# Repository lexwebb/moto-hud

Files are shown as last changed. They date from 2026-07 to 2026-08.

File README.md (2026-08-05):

# Moto HUD

Motorcycle e-ink turn-by-turn HUD: Android companion reads turn-by-turn from **OsmAnd** (AIDL or embedded Full Library) or Google Maps notifications + media, sends them over BLE to a Go service on a Raspberry Pi Zero that renders a sparse UI on a 250×122 panel ([Inky pHAT](https://shop.pimoroni.com/products/inky-phat) or [Waveshare 2.13″ B/W e-Paper HAT](https://www.waveshare.com/2.13inch-e-paper-hat.htm); optional LCD).

```
OsmAnd app  ──► AIDL (default) ───────────────┐
:osmand DF  ──► RoutingHelper (on-demand) ────┼─► Android app ──BLE──► Go (Pi) ──► display HAT
Google Maps ──► NotificationListener ─────────┤         ▲
Music apps  ──► MediaController ──────────────┘         │
Buttons (GPIO) ─────────────────────────────────────────┘  cmd notify
```

## Repo layout

| Path | Purpose |
|---|---|
| [`protocol/`](protocol/) | BLE UUIDs + JSON message schema |
| [`pi/`](pi/) | Go HUD service, mock injector, systemd unit |
| [`android/`](android/) | Kotlin companion app |
| [`enclosure/`](enclosure/) | OpenSCAD bench case (CAD + mesh exports) |
| [`site/`](site/) | Astro project site (GitHub Pages) |
| [`docs/adr/`](docs/adr/) | Architecture Decision Records |
| [`CONTEXT.md`](CONTEXT.md) | Domain language / glossary |

## Project site (GitHub Pages)

Public demos: enclosure 3D viewer, design HUD kit, WASM ride emulator.

**https://lexwebb.github.io/moto-hud/**

```bash
cd site
npm install
npm run build:wasm   # optional locally; needs Go — CI builds it for Pages
npm run dev          # http://localhost:4321/moto-hud/
```

Deploy: push to `main` (workflow `.github/workflows/pages.yml`). One-time: repo **Settings → Pages → Source: GitHub Actions**.

Go-backed live `/preview` (frame.png / fonts) is still local-only via `./scripts/emu.sh`.

Full ride simulation with Leaflet (OSM) + HUD driven by the same Go core (WASM preferred, HTTP fallback):

```bash
./scripts/emu.sh
# open http://127.0.0.1:8787/emulator/
```

- Map animates a real OSRM street route Whitehall → Farringdon (`web/emulator/routes/whitehall-farringdon.json`)
- Each tick posts nav distance/maneuver into the HUD
- Virtual Prev/Next/Action buttons
- **Device** picker: Inky 4-colour (~20s BWRY wipe), Waveshare B/W (partial ~0.3s, full ~2s every 5), or Display HAT Mini LCD (instant letterbox); e-ink modes use **≈ nearest 50 m** and redraw ~every **50 m**
- Build WASM only: `./scripts/build-wasm.sh` → `web/emulator/motohud.wasm` (gitignored, ~15MB)

## Hardware hosts

`motohud` talks to the panel/buttons/phone through `pi/internal/platform` ports so adapters can be swapped. Canonical compose is always **250×122 gray**; backends map to hardware.

| `-host` | Screen | Controls | Phone link |
|---|---|---|---|
| `auto` (default) | PNG, or Inky if `-inky` | keyboard / GPIO | BLE stub (or `-tags ble`) |
| `png` | PNG file | keyboard / GPIO | BLE stub |
| `inky` | Inky pHAT (kept for existing boards) | GPIO | BLE |
| `waveshare` | Waveshare 2.13″ B/W e-Paper | GPIO | BLE |
| `lcd` | Display HAT Mini 320×240 (letterboxed) | GPIO (Action→16) | BLE |
| `emu` | memory (+ optional PNG) | channel (injectable) | loopback linked |
| `test` | memory | channel | loopback |

```bash
./bin/motohud -demo -host png -out out/hud.png -http :8787
./bin/motohud -host inky -inky          # existing Inky on the Pi
./bin/motohud -host waveshare           # Waveshare 2.13 B/W
./bin/motohud -host lcd                 # Display HAT Mini (optional)
```

The browser emulator uses Go WASM (`pi/cmd/motohud-wasm`) for the HUD core, with HTTP → `-host emu` as fallback.

Reference pack from Claude Design lives in [`design/`](design/) (tokens, React kit, guidelines). **Production type is Terminus Bold**, not the kit’s browser monospace stand-in. Interactive mock: open `design/ui_kits/hud/index.html` via a static server.

Layouts live in [`assets/hud/`](assets/hud/) as 250×122 SVG with `{{placeholders}}`.

```bash
cd /Users/lex/src/moto-hud
./bin/motohud -demo -out out/hud.png
# open http://127.0.0.1:8787/preview/   ← 1-bit /frame.png @ 2×
# SVG source (debug): http://127.0.0.1:8787/frame.svg
```

**Typography (SVG + Terminus Bold):** Templates in `assets/hud/*.svg` use `<text data-pixel="12x24" font-size="24" …>`. At render those become **1×1 pixel `<rect>`s** from Terminus Bold BDFs; arrows are stroked then hard-thresholded to 1-bit. The web preview shows **`/frame.png`** (same raster as the Pi). Compare faces at `/preview/fonts.html`.

| Role | `data-pixel` | Face |
|---|---|---|
| Distance | `16x32` | `ter-u32b` |
| Road / titles | `12x24` | `ter-u24b` |
| Body / ETA | `8x16` | `ter-u16b` |
| Meta | `6x12` | `ter-u12b` |

Only those four sizes — no runtime scaling. License: SIL OFL 1.1 (`assets/fonts/terminus/OFL.TXT`).

```bash
cd pi
go run ./cmd/motohud -demo -out ../out/hud.png -http :8787
# another terminal:
go run ./cmd/mock-nav -scenario approach
# open out/hud.png — updates when distance crosses 500/200/100/50/20 m
```

Keyboard buttons while `motohud` runs: `p`/`n`/`a` short, `P`/`N`/`A` long (+ Enter).

**HUD UI layer** (`pi/internal/hudui`, ADR 0010–0012): [templ](https://templ.guide) screen components, integer flex layout helpers, and `hud.RenderEngine` for tier-aware draws (distance-only patches when the refresh orchestrator allows). Regenerate after editing `.templ` files: `./scripts/generate-hudui.sh`.

HTTP injector (also used by `mock-nav`):

- `POST /nav` — JSON nav message
- `POST /media` — JSON media message
- `POST /button` — body `prev` \| `next` \| `prev_long` \| `next_long` \| `action` \| `action_long` \| `skip_prev` \| `skip_next`

## Pi Zero + display HATs

### Recommended boards

| Role | Board | Notes |
|---|---|---|
| **Preferred new e-ink** | [Waveshare 2.13″ e-Paper HAT (black/white)](https://www.waveshare.com/2.13inch-e-paper-hat.htm) or [HAT+](https://www.waveshare.com/2.13inch-e-paper-hat-plus.htm) | Same 250×122 canvas; ~2s full / ~0.3s partial. **Do not** buy colour (B/G) variants — ~15s+ refresh. |
| Existing / regression | Inky pHAT **black/white** | Still supported via `-host inky`. B/W Inky is discontinued; 4-colour Inky is too slow for nav (~15–20s). |
| Optional LCD | [Pimoroni Display HAT Mini](https://shop.pimoroni.com/products/display-hat-mini) | 320×240 IPS; HUD letterboxed. Instant refresh; backlight + sun glare trade-offs. |

1. Enable SPI: `sudo raspi-config` → Interface → SPI (`dtparam=spi=on`).

   - **Waveshare 2.13″ HAT:** use default SPI0 **with hardware CE0**. Do **not** add `dtoverlay=spi0-0cs` — that leaves CS floating high and the panel stays blank while the driver still reports “ready”.
   - **Inky pHAT:** may need `dtoverlay=spi0-0cs` (soft CS); see Pimoroni docs.
   - Display HAT Mini uses **SPI0 CE1**; `dtparam=spi=on` is enough.

2. Cross-compile for the Pi (Docker; any host OS):

   ```bash
   ./scripts/build-armv6.sh           # stub BLE (pure Go)
   ./scripts/build-armv6.sh --ble     # real BlueZ peripheral (CGO)
   ./scripts/build-armv6.sh --ble --deploy 10.12.194.1   # scp + restart
   ```

   On-device `go build -tags ble` still works if you have Go + `libbluetooth-dev` on the Pi, but Docker is the supported path.

3. Run with hardware display:

   ```bash
   ./bin/motohud -host waveshare -out /tmp/hud.png -http :8787
   # or: -host inky    /  -host lcd
   ```

4. Install systemd unit from [`pi/systemd/motohud.service`](pi/systemd/motohud.service) (adjust paths/user).

**SD card from a Mac (Pi Zero W + Waveshare):** use **Raspberry Pi OS Lite** (32-bit / armhf) — not desktop. Flash + customise:

```bash
./scripts/flash-lite.sh --disk disk12 \
  --user motohud --password motohud \
  --ssid 'YourWifi' --psk '…' \   # 2.4 GHz only on Zero W
  --bwr                           # only if you have HAT (B) red/black/white
```

Or, with `bootfs` already mounted on an existing Lite card:

```bash
./scripts/prepare-bootfs.sh --boot /Volumes/bootfs \
  --user motohud --password motohud \
  --ssid 'YourWifi' --psk '…' \
  --bwr   # HAT (B) only
```

That writes an ARMv6 `motohud` binary, Waveshare SPI (hardware CE0 — never `spi0-0cs`), official USB Ethernet gadget (`rpi-usb-gadget`), cloud-init NetworkManager Wi‑Fi, and a firstrun installer. Use the Zero’s **data** micro‑USB port (next to HDMI), not PWR. Wait for **two** boots (~2–4 min).

**SSH over USB (recommended first):** macOS Sequoia/Tahoe cannot Internet‑Share to this gadget (`CHANNEL_IO` → no `bridge100`). Skip Sharing; run:

```bash
./scripts/macos-usb-gadget.sh   # 10.12.194.2/28, no gateway; Wi‑Fi stays default route
ssh motohud@10.12.194.1         # Pi SHARED address
```

Then mDNS / Wi‑Fi: `ssh motohud@motohud.local`. HTTP: `http://10.12.194.1:8787/`.

**BLE (phone link):** `flash-lite` / `prepare-bootfs` build a BlueZ binary via Docker by default. To refresh a running Pi:

```bash
./scripts/build-armv6.sh --ble --deploy 10.12.194.1
```

Android companion scans for BLE name **MotoHUD**.

### Display pin maps (BCM)

Avoid these for buttons:

| Backend | DC | RST | BUSY / other | SPI |
|---|----|-----|---|-----|
| Inky | 22 | 27 | BUSY 17 | SPI0.0 |
| Waveshare 2.13 | 25 | 17 | BUSY 24 | SPI0.0 |
| Display HAT Mini | 9 | — | BL **13**, CE1 | SPI0.1 |

### Button wiring (BCM)

Active-low with internal pull-ups. Full soldering dummies guide, enclosure BOM, and Waveshare 8-pin note: [`docs/BUTTONS.md`](docs/BUTTONS.md). Caps + tactile wells: [`enclosure/README.md`](enclosure/README.md).

| Button | BCM (inky / waveshare) | BCM (`-host lcd`) | Role |
|---|---|---|---|
| Prev | 5 | 5 (HAT A) | Previous screen / prev track on Media |
| Next | 6 | 6 (HAT B) | Next screen / next track on Media |
| Action | 13 | **16** (HAT X) | Context action; **long-press** → Nav home |

On Display HAT Mini, BCM 13 is the backlight, so Action automatically remaps to button X (16).

Screens: **Nav** → **Media** → **Status**.

- Prev/Next (not on Media) → change screen  
- Media + short Prev/Next → skip track (`prev_track` / `next_track`)  
- Media + long Prev/Next → change screen  
- Media + Action → `play_pause`  
- Status + Action → force full redraw  
- Long-press Action → Nav home

## Android companion

Open [`android/`](android/) in Android Studio, sync Gradle, side-load on a phone (or emulator).

**Delivery model** ([ADR 0006](docs/adr/0006-engine-agnostic-nav-android-osmand-ios-mapkit.md)):

| Piece | Size (approx) | Nav |
|---|---|-----|
| Base APK | ~6.5 MB | External [OsmAnd](https://play.google.com/store/apps/details?id=net.osmand) via AIDL + Maps scrape fallback |
| On-demand `:osmand` module | ~215 MB uncompressed (arm64-only, mini basemap stripped); Play compresses further | OsmAnd Full Library — lanes, then-next, ETA |
| Full debug `.aab` (base+module) | ~100 MB | both modules packaged; Play still delivers base first |
| Region maps | downloaded in OsmAnd UI | not bundled |

```bash
# base APK (AIDL)
gradle :app:installDebug

# Play / local module testing — build an App Bundle, then:
gradle :app:bundleDebug
# bundletool build-apks --bundle=app/build/outputs/bundle/debug/app-debug.aab \
#   --output=/tmp/motohud.apks --local-testing
# bundletool install-apks --apks=/tmp/motohud.apks
```

1. Install **OsmAnd** for the default AIDL path (or skip if you only use Maps scrape).
2. Optional: tap **Download rich OsmAnd nav** → restart when prompted → **Open OsmAnd map** → download your region → navigate (lanes on the HUD).
3. Grant **notification access** (media + Maps/OsmAnd enrichment).
4. Tap **Start HUD link** — starts the nav engine, scans for BLE **MotoHUD**.

Size knobs: arm64-only natives, Play Feature Delivery on-demand module, `World_basemap_mini.obf` stripped (maps stay dynamic), AAB ABI/language/density splits.

If using Maps and fields are empty, disable Maps **Live Updates** / **Live info** notification categories. iOS will use MapKit later (no self-hosted Valhalla).

**Dev HTTP (no Pi BLE):** enable **Also POST nav/media over HTTP** and set the base URL (emulator → host is `http://10.0.2.2:8787`). Run `motohud -host png -http :8787` on the PC. BLE scan still runs; HTTP posts happen whenever nav/media update. See [`protocol/README.md`](protocol/README.md).

Unit tests: `gradle :app:testDebugUnitTest`.

## CI

[`.github/workflows/ci.yml`](.github/workflows/ci.yml) runs `go test ./...` in `pi/` and Android unit tests on push/PR.

## Notes

- Panel refresh is full-frame on Inky (~20s). Waveshare uses partial updates (~0.3s, no flicker) with a full refresh (~2s) every 5 frames to clear ghosting. The Go compositor only redraws on maneuver/road changes, coarse distance thresholds, screen changes, or force.
- Audio stays on the phone → helmet Bluetooth; the Pi is display + button bridge only.

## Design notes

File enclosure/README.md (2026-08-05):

# Moto HUD enclosure (bench prototype)

Parametric OpenSCAD clamshell for a **Raspberry Pi Zero + e-ink HAT** stack (Inky or Waveshare 2.13″). Buttons are a right-hand rail: printed mushroom caps over 6×6 mm tactiles by default. No bike mount or full weather sealing yet — fit the boards and switches first.

## Files

| Path | Purpose |
|---|---|
| [`moto_hud_case.scad`](moto_hud_case.scad) | Parametric model (`part`: `assembly` / `base` / `lid` / `caps`) |
| [`preview.html`](preview.html) | Standalone Three.js orbit viewer (dev convenience) |
| [`exports/`](exports/) | STL / GLB meshes for print + site |

The project site hosts the enclosure viewer at
**https://lexwebb.github.io/moto-hud/enclosure/** (copies `exports/assembly.glb` at build time).
After regenerating meshes, commit the updated GLB so CI/Pages pick it up.

## Buttons

| `button_mode` | Lid | Base | Extra print |
|---|-----|---|---|
| **`cap`** (default) | Stem shafts + outer flange counterbore | 6×6 tactile wells + wire channels into the board cavity | `part="caps"` — three ~11 mm mushroom actuators |
| **`panel8`** | 8.2 mm holes for high-head metal panel switches | No wells | None |

Order along +Y (rail on the **right**, screen upright): **Prev → Next → Action** (BCM 5 / 6 / 13). Wiring guide: [`docs/BUTTONS.md`](../docs/BUTTONS.md).

### Cap fit loop

1. Print base, lid, and caps. Dry-fit stems — they should slide, not bind (`stem_clear` / `print_tol`).
2. Seat 6×6 momentary NO tactiles in the wells; route pigtails through the wire channels.
3. Drop caps in from the outside (flange in the counterbore). Stem should click the tactile before bottoming on the lid.
4. If the click is early/late, change **`stem_len`** or **`well_depth`** only — do not change BCM pins.
5. Caliper the real tactile height into **`tactile_h`** after you buy parts.

Caps: TPU (~95A) for a softer dome, or PETG for a rigid v0. Export with stem toward the bed (`caps_sprue` lifts geometry so stem tips sit near Z=0) or flip in the slicer.

## Dimensions (defaults)

Tune the Customizer / parameter block after caliper checks:

- Pi Zero board: **65 × 30 mm**, M2.5 holes inset **3.5 mm**
- Stack height (Pi + header + HAT): **14 mm** (`stack_h`)
- Usable glass: **48.5 × 23.8 mm** (`window_w` / `window_d`)
- Wall / floor / lid: **2 mm**; lateral clearance **0.4 mm**
- Right-hand **button rail**: **12 mm** (`button_rail`); pitch **12 mm**; cap OD **11 mm**

## OpenSCAD

1. Install [OpenSCAD](https://openscad.org/) (2021.01+).
2. Open `moto_hud_case.scad`.
3. Set **part** to `assembly` for preview (optional **explode** to lift the lid).
4. **F5** preview, **F6** render.

### Export STLs (GUI)

1. Set `part` to `base`, `lid`, or `caps`, **F6**, then **File → Export → Export as STL**.
2. For the browser preview, export `part = "assembly"` to `exports/assembly.stl`, then convert to GLB (below).

### Export STLs (CLI)

From this directory (quoting matters on Windows `cmd`):

```bat
"C:\Program Files\OpenSCAD\openscad.exe" -D "part=\"base\"" -o exports/base.stl moto_hud_case.scad
"C:\Program Files\OpenSCAD\openscad.exe" -D "part=\"lid\"" -o exports/lid.stl moto_hud_case.scad
"C:\Program Files\OpenSCAD\openscad.exe" -D "part=\"caps\"" -o exports/caps.stl moto_hud_case.scad
"C:\Program Files\OpenSCAD\openscad.exe" -D "part=\"assembly\"" -o exports/assembly.stl moto_hud_case.scad
```

macOS / Linux:

```bash
openscad -D 'part="base"' -o exports/base.stl moto_hud_case.scad
openscad -D 'part="lid"' -o exports/lid.stl moto_hud_case.scad
openscad -D 'part="caps"' -o exports/caps.stl moto_hud_case.scad
openscad -D 'part="assembly"' -o exports/assembly.stl moto_hud_case.scad
```

Or run [`export_meshes.sh`](export_meshes.sh) / [`export_meshes.ps1`](export_meshes.ps1) (includes `caps` + GLB).

### Assembly GLB for the browser viewer

OpenSCAD does not export GLB; convert the assembly STL (needs `pip install trimesh`):

```bash
python -c "import trimesh; m=trimesh.load('exports/assembly.stl', force='mesh'); from trimesh.visual.material import PBRMaterial; from trimesh.visual import TextureVisuals; m.visual=TextureVisuals(material=PBRMaterial(baseColorFactor=[0.72,0.74,0.76,1], metallicFactor=0.05, roughnessFactor=0.55)); m.export('exports/assembly.glb')"
```

## Browser preview

Primary viewer: the Astro site page (`site/` → `/enclosure/` on Pages).

Standalone convenience viewer ([`preview.html`](preview.html)) still works:

```bash
# from repo root
python -m http.server 8765 --directory enclosure
# open http://127.0.0.1:8765/preview.html
```

After changing the `.scad`, re-export meshes (including `assembly.glb`) and refresh / redeploy the site.

## Print notes

- Print **base**, **lid**, and **caps** separately. Lid export is already flipped upright with lip up.
- Start with the default clearances; if the board is tight, bump `clearance` / `print_tol` by 0.1–0.2 mm.
- USB cutout sized for Pi Zero micro-USB power; widen `usb_w` / `usb_h` for Zero 2 W USB-C if needed.

## Next (not in this pass)

- Bike mount interface (after you measure the mount area)
- Weather sealing / lens / silicone skirt over caps
- Handlebar remote pod (large switches; same BCM map)

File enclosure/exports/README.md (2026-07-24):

# Exported meshes for print + browser preview.
# Regenerate from ../moto_hud_case.scad (see ../README.md).

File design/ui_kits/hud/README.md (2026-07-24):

# HUD UI Kit

Interactive walkthrough of all six delivered screens at true 250×122 (scaled 2.4× for viewing). Buttons below the panel simulate the device's three physical controls: Prev / Next / Action, with mousedown+hold (~500ms) standing in for long-press.

Screens: NavActiveNoRibbon, NavActiveRibbon, NavIdle, MediaFocus, StatusDiagnostics, NavMediaHybrid — each a thin composition of the `components/` primitives (ManeuverGlyph, DistanceReadout, RoadRibbon, etc). No new visual logic lives here beyond layout.

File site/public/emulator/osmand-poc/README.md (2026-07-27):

# OsmAnd junction proof (no phone)

Off-device proof that **OsmAnd-java** (same library the embedded Full Library module uses) can supply junction IR inputs: `attachedRoutes`, `highway`, `oneway`, bearings — without the tagged Overpass bake.

## Result (Whitehall → Farringdon)

See [`osmand-junction-dump.json`](osmand-junction-dump.json). Summary from last run:

- **9** turn segments; **7** with non-empty `getAttachedRoutes(start)`
- **`dual_carriageway` tag hits: 0** — tag is not in OBF routing encoding
- **`dual_inferred: 3`** — Whitehall (×2) + Northumberland Avenue via spatial OBF scan
- Side streets / Farringdon / Embankment: no dual (aligned with OSM tags; Embankment is physically dual but untagged)

## Dual inference rules (hardened)

`attachedRoutes` alone miss clean duals (parallel carriageways often share no nodes). Algorithm:

1. **Turn corridor only** — skip residential / `*_link` turn segments.
2. **Local arms** — route segment + attachments at every point index.
3. **Spatial OBF scan** (~50 m) via `buildSearchRouteRequest` / `loadRouteIndexData` — required for Whitehall-class duals.
4. **Match** when:
   - both car highways (exclude footway/cycleway/pedestrian)
   - lateral cross-track sep **10–22 m**
   - opposite travel bearings (≥150°)
   - **and** at least one `oneway≠0` (both-bidirectional parallels → Farringdon FP)
5. **Opposite oneway** means both oneway + opposite bearings (each dual carriageway is typically `oneway=+1` along its own geometry — do **not** require `+1` vs `-1` signs).
6. Never same-direction parallels (Fleet Street).

## Reproduce

Prereqs: JDK 17+, network once for Overpass + MapCreator download.

```bat
:: from site/
node scripts/export-whitehall-osm.mjs

:: download MapCreator if missing (~150MB)
curl -fL -o public/emulator/osmand-poc/OsmAndMapCreator-main.zip https://download.osmand.net/latest-night-build/OsmAndMapCreator-main.zip
:: extract to public/emulator/osmand-poc/mapcreator/

cd public/emulator/osmand-poc/mapcreator
utilities.bat generate-roads ..\whitehall-farringdon.osm

cd ..
dump-osmand-junction.bat
```

## What this means for the plan

| Need | Source on phone (Full Library) | Proven here? |
|---|---|---|
| Turn class | `TurnType` | Yes (KL/TR/TL/TSLR/…) |
| Side arms | `RouteSegmentResult.getAttachedRoutes` | Yes |
| Highway class / ramps | `RouteDataObject.getHighway()` | Yes (`primary_link`, etc.) |
| Divided road | Spatial OBF + oneway/bearing | **Yes** (no tag) |
| Full OSM bake | Not required | Confirmed unnecessary for junction node |

AIDL path still cannot do this; only embedded OsmAnd.

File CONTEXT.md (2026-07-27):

# Moto HUD — domain language

Terms meaningful to the product. Implementation details live in code and ADRs.

| Term | Meaning |
|---|---|
| **Companion** | Phone app that ingests navigation + media and sends HUD state to the Pi over BLE (or dev HTTP). |
| **Hub** | Go service on the Pi: applies nav/media, composites frames, drives the panel, handles buttons. |
| **Canvas** | Logical 250×122 grayscale HUD frame before a display backend maps it to hardware. |
| **Host / backend** | Panel adapter selected with `-host` (`inky`, `waveshare`, `lcd`, `png`, …). |
| **Nav engine** | Platform-specific source of turn-by-turn data that fills the shared `nav` protocol (e.g. OsmAnd on Android, MapKit on iOS). |
| **Maneuver** | Next turn class on the wire: `left`, `right`, `slight_*`, `straight`, `u_turn`, `roundabout`, `arrive`, `depart`, `unknown`. |
| **Lanes** | Optional per-lane guidance array on `nav`; omitted when the engine cannot provide it. |
| **Refresh gate** | Policy that limits e-ink redraws (maneuver/road change, coarse distance buckets, force). |
| **Partial / full refresh** | Waveshare B/W update modes (~0.3s quiet vs ~2s wipe); full after every N partials. |
| **Junction IR** | Semantic turn-scene description (`nav.junction`) drawn as idealized templates by `kind`; replaces geographic minimap polylines ([ADR 0013](docs/adr/0013-junction-ir-replaces-minimap.md)). |
| **Ribbon** | Secondary left-column corridor schematic when neither junction nor synthesizable maneuver exists. |
| **Link** | BLE (or HTTP injector) connection carrying `nav`, `media`, `cmd`, `heartbeat`. |

Decisions: [`docs/adr/`](docs/adr/).

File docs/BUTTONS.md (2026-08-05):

# Button wiring

Canonical buttons are active-low to GND with software pull-ups. Display HATs reserve some GPIOs — do not reuse those for buttons.

The Waveshare 2.13″ **PH2.0 8-pin cable is display-only** (VCC/GND/SPI/DC/RST/BUSY). It is **not** a button bus. Wire external momentary NO switches to free GPIOs instead.

## Default button map (Inky / Waveshare)

| Function | BCM | Physical pin (Pi Zero underside) | Suggested wire |
|---|-----|---|---|
| Prev | 5 | **29** | Green |
| Next | 6 | **31** | Yellow |
| Action | 13 | **33** | Blue |
| Common GND | — | **30** or **34** | Black |

| Gesture | Effect |
|---|---|
| Short Prev/Next | Change screen (or skip track on Media) |
| Long Prev/Next (≥800 ms) | Always change screen |
| Short Action | Context (play/pause or force redraw) |
| Long Action | Return to Nav home |

Enclosure rail order (+Y, rail on the right): **Prev → Next → Action**. See [`enclosure/README.md`](../enclosure/README.md).

## Switch BOM (matches enclosure SCAD)

| Tier | What | Notes |
|---|---|---|
| **HUD lid (default)** | 6×6 mm **sealed / IP67** momentary NO tactile ×3 + printed caps (`part="caps"`) | Glove target is the ~11 mm print; electrical is the tactile |
| **Fallback** | 8 mm **high-head** metal momentary 1NO, IP65–IP67 | Set `button_mode = "panel8"` in OpenSCAD; no caps/wells |
| **Bar pod only (later)** | OTTO P9 / 12 mm high-head | Too big for the Pi Zero lid |
| **Avoid** | Flush open tactiles with no proud cap; latching (on/off) switches | Misses in gloves; wrong semantics |

Electrical: momentary NO → GND only. Soft pull-ups are enabled in software. Measure real tactile height and update `tactile_h` in the SCAD after purchase.

## Dummies soldering guide (Pi Zero + stacked HAT)

### What you need

- Fine tip soldering iron (~350 °C), thin solder, flux
- 4 lengths of flexible wire (~24–28 AWG, stranded), ~15–30 cm — colour-code them
- Multimeter (continuity); heat-shrink or Kapton
- Three 6×6 mm momentary NO tactiles (or 8 mm panel switches for `panel8`)

### Orient the board

1. Power off, unplug USB. Pads are on the **bottom** of the Zero (header solder side).
2. Find **pin 1**: the only **square** pad, nearest the **microSD** end.
3. With the SD end toward you and the header along the long edge facing you:

```
        SD card end ← toward you
   (odd row, toward board centre)     (even row, toward board edge)
        1  3  5  …  27  29  31  33  35  37  39
        2  4  6  …  28  30  32  34  36  38  40
```

Even pins sit along the **outer board edge**. Odds sit one row inward. Cross-check: [pinout.xyz](https://pinout.xyz/).

**Do not solder** Waveshare display pins: physical **19** (MOSI), **23** (SCLK), **24** (CE0), **22** (BCM25/DC), **11** (BCM17/RST), **18** (BCM24/BUSY).

### Solder steps

1. Strip ~2 mm; tin the wire tip.
2. Flux the pad. Iron to pad + wire; tiny solder — shiny cone, no bridge.
3. Solder **GND first** (30 or 34), then 29, 31, 33.
4. Loupe-check: no bridge to the neighbour (especially 31↔32).
5. Continuity (power still off): wire ↔ pad beep; wire ↔ neighbour **no** beep.
6. Heat-shrink / strain-relieve where the four wires leave the board.
7. Restack the HAT. Route wires through the enclosure **wire channels** into the tactile wells (or out a notch for bare-board tests).

### Connect the switches

Each tactile: terminal A → coloured signal; terminal B → shared black GND (daisy-chain). Ignore LED leads on illuminated parts for now.

When pressed, the GPIO is pulled to GND; `buttons.Start` treats low as pressed.

### Bench smoke test

```bash
./bin/motohud -host waveshare -http :8787
```

Expect logs `buttons: watching prev (GPIO5)` / `next (GPIO6)` / `action (GPIO13)`. Short Prev/Next cycles screens; long Action returns to Nav. Control without GPIO:

```bash
curl -X POST -d next http://127.0.0.1:8787/button
```

## Per-display reserved pins (BCM)

### Inky pHAT (`-host inky`)

| Signal | BCM |
|---|-----|
| BUSY | 17 |
| RESET | 27 |
| DC | 22 |

SPI0 CE0. Leave buttons on 5 / 6 / 13.

### Waveshare 2.13″ B/W (`-host waveshare`)

| Signal | BCM |
|---|-----|
| DC | 25 |
| RST | 17 |
| BUSY | 24 |

SPI0 CE0. Leave buttons on 5 / 6 / 13. The HAT’s 8-pin PH2.0 is the same SPI/control set for remote mounting — not buttons.

### Display HAT Mini (`-host lcd`)

| Signal | BCM |
|---|-----|
| DC | 9 |
| Backlight | **13** |
| SPI | SPI0 CE1 |

Onboard buttons: A=5, B=6, X=16, Y=24. Soft Action remaps to **16** (X) because 13 is backlight. Prev/Next stay 5/6 (A/B).

## Waterproofing (later)

Printed caps are actuators only — not the electrical contact. Next steps: IP67 sealed tactiles in the same wells and/or a silicone skirt over the caps; base/lid gasket; optional remote handlebar pod with larger switches on the same BCM map.

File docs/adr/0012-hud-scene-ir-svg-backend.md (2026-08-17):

---
status: accepted
date: 2026-07-27
---

# HUD scene IR; bitmap is the only rasterizer

Compose, refresh plans, and patches produce a small **integer scene graph** (1-bit black/white on 250×122). **`hudui/render/bitmap`** is the sole path from scene → `*image.Gray` — full frames (`compose.FrameDocument`), patch layers, minimap/junction panes, Pi, and WASM. **`hudui/render/svg`** serializes scene → SVG markup for `/frame.svg`, designer export, and lab debug strings only — it does not rasterize.

## Considered options

- **Chosen** — scene IR + `render/bitmap` everywhere pixels are produced.
- **Rejected: SVG/`canvas` on the hot path** — megabyte allocs; blocked MCU ports; WASM paid the same cost.
- **Rejected: HTML/CSS runtime** — ADR 0010; fights partial-refresh slots.

## Consequences

- `tdewolff/canvas` is not a runtime dependency of `motohud` / WASM.
- `RawSVG` nodes fail bitmap rasterize; production compose must emit typed nodes.
- Related: [0010](0010-hud-ui-templ-component-layout.md), [0011](0011-component-refresh-tiers-partial-regions.md).

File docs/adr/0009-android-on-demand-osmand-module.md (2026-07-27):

---
status: accepted
date: 2026-07-27
---

# Android: small base APK + on-demand OsmAnd Full Library module

Ship the companion as a **~6.5 MB base** (AIDL + Maps scrape) and put OsmAnd Full Library in a Play Feature Delivery **on-demand** module (`:osmand`). Shrink that module with **arm64-only** natives, **stripped `World_basemap_mini.obf`**, and **AAB ABI/language/density splits**. Region maps stay runtime downloads inside OsmAnd.

## Considered options

- **Chosen** — base AIDL always; download Full Library when the rider wants lanes / then-next; restart so `AppComponentFactory` can switch to `OsmandApplication`.
- **Rejected: monolithic embedded flavor (~370 MB)** — unacceptable default install for a BLE companion.
- **Rejected: Full Library in the base APK with only ABI filters** — still ~150 MB+ before first launch.
- **Rejected: self-hosted `.so` CDN outside Play modules** — brittle version coupling to OsmAnd AARs.

## Consequences

- Rich nav needs Play (or `bundletool --local-testing` for sideload); plain `installDebug` is base-only unless the module is fused/tested via bundletool.
- After module install, the process must restart so `MotoHudAppComponentFactory` can load `MotoHudOsmandApp`.
- Emulators without arm64 cannot run the Full Library module; they keep using AIDL.

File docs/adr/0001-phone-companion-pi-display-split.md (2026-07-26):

---
status: accepted
date: 2026-07-01
---

# Phone companion owns nav/media; Pi is display + buttons hub

The motorcycle HUD splits work: an Android (later iOS) **companion** reads navigation and media on the phone and pushes state over BLE; a Go **hub** on a Raspberry Pi Zero composites the 250×122 frame, drives the panel, and sends button `cmd`s back for media control. Audio stays on the phone → helmet Bluetooth.

## Considered options

- **Chosen** — thin Pi, smart phone (scrapers / nav engines already live there).
- **Rejected: all routing on Pi** — Pi Zero is a weak host for maps/search/reroute; phone already has GPS and app ecosystems.
- **Rejected: phone-only HUD** — e-ink / handlebar mount wants a dedicated low-power panel off the phone UI.

## Consequences

- Protocol and companion quality dominate nav richness; the Pi must not assume a single phone OS or engine.
- Dev HTTP injector can stand in for BLE while bringing up the hub.

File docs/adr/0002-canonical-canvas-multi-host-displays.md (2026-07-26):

---
status: accepted
date: 2026-07-26
---

# Canonical 250×122 canvas with swappable display hosts

Compositing always targets a **250×122 grayscale** canvas. Hardware differences are isolated behind `-host` adapters (`inky`, `waveshare`, `lcd`, `png`, `emu`, `test`) so layout, WASM emulator, and protocol stay shared.

## Considered options

- **Chosen** — one logical resolution; letterbox or dither at the adapter (LCD 320×240 letterboxes the HUD).
- **Rejected: native resolution per panel** — would fork layouts and emulator profiles per SKU.

## Consequences

- LCD Action button remaps to BCM 16 because Display HAT Mini backlight uses 13 (see `docs/BUTTONS.md`).
- Emulator device picker mirrors the same host profiles (timing + chrome).

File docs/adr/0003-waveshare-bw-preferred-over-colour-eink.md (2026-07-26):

---
status: accepted
date: 2026-07-26
---

# Prefer Waveshare 2.13″ B/W over colour e-ink for navigation

Four-colour Inky pHAT (BWRY) full refresh is ~15–20s even when the framebuffer is only black/white — too slow for turn-by-turn. **Waveshare 2.13″ black/white** (~2s full, ~0.3s partial) is the preferred new e-ink SKU. Existing Inky boards remain supported via `-host inky` for prototyping.

## Considered options

- **Chosen** — Waveshare B/W as preferred e-ink; keep Inky path.
- **Rejected: colour e-ink for nav** — flash duration dominates usefulness.
- **Rejected: LCD-only** — optional via `-host lcd`, not the primary product look.

## Consequences

- Pinouts differ (Waveshare DC=25 RST=17 BUSY=24 vs Inky); docs and platform wiring must stay per-host.
- Do not buy Waveshare colour (B/G) variants for this project.

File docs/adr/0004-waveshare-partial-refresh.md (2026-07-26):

---
status: accepted
date: 2026-07-26
---

# Waveshare: partial refresh with full clean every 5 frames

The Waveshare 2.13″ B/W driver uses **partial** updates (~0.3s, no flicker) for ordinary gated redraws, and a **full** refresh (~2s, multi-flash) for the base image and every 5th update thereafter, per vendor guidance against ghosting. Emulator Waveshare profile matches this cadence.

## Consequences

- Re-init before leaving partial mode for a global refresh (Waveshare FAQ).
- Inky remains full-frame only; LCD is instant (no e-ink gate timing).

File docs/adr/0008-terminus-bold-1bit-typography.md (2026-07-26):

---
status: accepted
date: 2026-07-01
---

# Terminus Bold pixel fonts, four sizes, 1-bit output

HUD text is rendered from **Terminus Bold** BDF faces at fixed `data-pixel` sizes (16×32, 12×24, 8×16, 6×12) into hard-thresholded 1-bit frames. No runtime font scaling. Design-kit browser monospace is a stand-in only.

## Considered options

- **Chosen** — Terminus Bold (SIL OFL) for crisp e-ink glyphs.
- **Rejected: scalable outline fonts on device** — soft edges and size sprawl fight 250×122 1-bit.

## Consequences

- SVG templates use placeholder text + `data-pixel`; production path is rect glyphs → PNG/panel.
- Preview and Pi must share the same raster path (`/frame.png`).

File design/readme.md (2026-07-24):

# Moto HUD Design System

## What this is
A visual system for a **motorcycle heads-up display** on a 2.13" e-ink panel — 250×122px, 1-bit black-on-white, no touch, three physical buttons (Prev / Next / Action, long-press Action = home/Nav). The phone runs Google Maps + music; this tiny Raspberry-Pi-class panel shows only distilled state pushed over BLE. There is no existing brand, codebase, or Figma file behind this — the system was designed from scratch against the hardware brief supplied in the project's initial prompt (reproduced in full in the original task; see "Data we have" below for the operative constraints).

This is not a phone UI, not CarPlay, not a moving map. Treat it as an **instrument face**: a glance-readable panel like a speedometer, not a screen you interact with.

## Data we actually have (design boundary)
Phone → HUD packets:
- **Navigation**: active y/n; maneuver type (left/right/slight-left/slight-right/straight/u-turn/roundabout/arrive/depart/unknown); distance_m + short distance_text; road name/instruction string; optional eta_min
- **Media**: playing y/n; title; artist
- **Link**: BLE connected y/n; heartbeat

No live map tiles, no continuous GPS track, no full turn list, no album art, no bike telemetry (v1), no touch/voice. See `guidelines/data-scope.card.html` for the excluded-vs-reserved breakdown.

## Components (10)
- **glyphs/** — `ManeuverGlyph` (10 maneuver types, pixel-grid arrows), `ConnectionMark` (BLE link + heartbeat blink)
- **readouts/** — `DistanceReadout` (hero number), `ETAReadout`, `MediaLine` (now-playing title/artist)
- **navigation/** — `RoadRibbon` (schematic corridor band, reserved for the road-view stretch feature), `ProgressTicks` (coarse distance ticks)
- **chrome/** — `ModeHeader` (mode label + link mark), `FooterHints` (≤11px button legend)
- **core/** — `PixelDivider` (solid/dashed/dither rule)

### Intentional additions
This system has no prior component inventory to enumerate (no attached codebase/Figma), so the primitive set above was authored from scratch, sized to what an e-ink instrument panel actually needs — not a generic web kit. There is deliberately no Button/Input/Card/Dialog: the device has no touch surface, so standard interactive web primitives don't apply.

## UI kit
`ui_kits/hud/` — all six delivered screens, interactive (click Prev/Next/Action, hold for long-press):
1. Nav active — no ribbon
2. Nav active — with road-view ribbon
3. Nav idle / waiting for route
4. Media focus
5. Status / link diagnostics
6. Nav + media hybrid

## Index
- `styles.css` — root stylesheet, `@import`s only
- `tokens/colors.css`, `typography.css`, `spacing.css`, `patterns.css` — design tokens
- `components/glyphs/`, `components/readouts/`, `components/navigation/`, `components/chrome/`, `components/core/` — the 10 primitives, each with `.jsx` + `.d.ts` + `.prompt.md` + a `.card.html` demo
- `guidelines/` — foundation specimen cards: colors, type scale/weights, spacing scale, panel grid, stroke weights, hierarchy/eye-path, data scope
- `ui_kits/hud/` — the six screen compositions + interactive `index.html`
- `thumbnail.html` — project tile
- `SKILL.md` — portable skill for Claude Code / other agents

## Content fundamentals
Copy on the panel is functional, not conversational — it's an instrument, not an assistant. No "you" address, no first person, no punctuation flourish. Road names and instructions are passed through verbatim from the phone (e.g. "Ridge Rd", "onto Harbor Blvd") — never rewritten or softened. Units render as short suffixes (m, km, min) directly beside numbers, never spelled out. No emoji, ever — a dashboard doesn't smile. The only invented copy is chrome: mode labels are one word, all-caps, 11px (NAV / MEDIA / STATUS); footer hints are `BUTTON + one-word verb` (PREV Mode, NEXT Skip, HOLD Home, ACTION Redraw). Idle/empty states state the fact plainly ("Waiting for route…") rather than being cute about it.

## Visual foundations
- **Color**: exactly two values, `--ink` (#000) and `--paper` (#fff) — this is a 1-bit display, there is no gray. Where a "quiet"/disabled/ghost state is needed, use a **dither pattern** (checkerboard, see `--dither-25`/`--dither-50`/`--hatch` in `tokens/patterns.css`) instead of opacity or a lighter color — opacity doesn't exist on e-ink.
- **Type**: a single pixel-grid family (Terminus Bold, bold BDF faces) at four fixed sizes — 12 (meta/footer), 16 (road/ETA), 24 (titles), 32 (hero distance). No sizes in between; no other families. Bold = signal (numbers, labels), Regular = context (road names, secondary meta).
- **Spacing**: small-integer scale (2/4/6/8/12/16px) — the panel is 250×122, an 8px web grid is too coarse.
- **Backgrounds**: flat paper white, full-bleed. No images, no photography, no gradients — a 1-bit panel can't render either.
- **Icons/glyphs**: hand-built on a 40×40 pixel grid, 3px square-capped strokes, miter joins — no rounded caps (rounding anti-aliases on rasterization). See Iconography below.
- **Animation**: none, except a single discrete on/off blink (`steps(1)`, ~1.6s) on the BLE heartbeat dot. No fades, no easing curves, no smooth transitions anywhere — the panel's refresh is a full 1–2s redraw, so anything implying continuous motion (a smoothly filling progress bar, a scrolling ribbon) is a lie the hardware can't back up. `ProgressTicks` and `RoadRibbon` both step in discrete jumps at coarse thresholds instead.
- **Hover/press states**: not applicable — no touch, no cursor. The only "state" feedback is the physical button legend in `FooterHints`.
- **Borders**: solid black rules only, 1px (dividers) / 2px (bold rules, ticks) / 3px (glyph strokes) — never a hairline that could vanish on threshold-to-1-bit conversion.
- **Corners**: square, everywhere. No border-radius on anything — an instrument face, not a phone app.
- **Cards/shadows/blur/transparency**: none of these exist in this system. No drop shadows, no blur, no translucency — all of that requires gray or alpha, which 1-bit e-ink doesn't have.
- **Layout**: fixed, not responsive — every screen is composed against the literal 250×122 canvas (see `guidelines/panel-grid.card.html`), with a reserved 34–40px horizontal band for the road-view ribbon so it can be added without restructuring the nav screens.
- **Imagery**: none — no photos, no illustration, no album art (the phone doesn't send any).

## Iconography
No icon library, no icon font, no CDN glyph set, no emoji, no Unicode symbol substitution — every glyph on the panel (maneuver arrows, play/pause, link/heartbeat marks) is a **hand-built vector on a pixel grid**, authored directly in `components/glyphs/ManeuverGlyph.jsx` and `ConnectionMark.jsx` using plain SVG `line`/`polygon`/`path`/`circle`. This is a deliberate exception to "never draw your own icons": there is no existing brand or icon system to source from, and the maneuver/status glyphs are core functional content the brief explicitly asks this system to define (a "component sheet" of maneuver glyphs). Rules for any new glyph: 40×40 (or 12×12 for marks) viewBox, 3px (or 1.6px for marks) square-capped strokes, miter joins, no curves except the u-turn/roundabout arcs, `shape-rendering:crispEdges` for preview. Production art gets thresholded to 1-bit by a separate raster pipeline — these SVGs are the vector source, not the shipped bitmap.

## Logo / brand mark
No company or product brand was provided — this is a from-scratch hardware concept, not an existing company. No logo exists and none was invented. Where a mark might normally sit (the Nav-idle empty state), the product is referred to in plain type as "MOTO HUD," set in the same pixel font as everything else — a descriptive label, not a designed wordmark. If this becomes a real product with a name/mark, replace that one string.

## Font substitution note
No existing typeface was specified (from-scratch build). **Terminus Bold** (Google Fonts, bold BDF faces) was chosen as the system's only typeface because it's designed natively as a pixel/bitmap font — it renders as clean whole-pixel strokes at small sizes without anti-aliasing, which is the actual hardware requirement here. Production rasters Terminus Bold BDFs (`ter-u12b` / `16b` / `24b` / `32b`, SIL OFL). This design kit uses a monospace stand-in in the browser; sizes match the BDF pixel sizes.

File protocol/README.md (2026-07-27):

# Moto HUD Protocol

JSON messages over BLE GATT (phone ↔ Pi) and the same JSON over the **dev HTTP injector** on the Pi.

Device advertises as **MotoHUD**.

## UUIDs

See [uuids.json](uuids.json). Shared constants also live in:

- Go: `pi/internal/protocol/protocol.go`
- Kotlin: `android/.../Protocol.kt`

| Role | Direction | Characteristic |
|---|---|---|
| `nav` | Phone → Pi (write) | navigation state |
| `media` | Phone → Pi (write) | now playing |
| `cmd` | Pi → Phone (notify) | media commands from buttons |
| `heartbeat` | Phone → Pi (write) | keep-alive (~15s); also used as link presence |

## Messages

### `nav`

```json
{
  "type": "nav",
  "active": true,
  "instruction": "Turn left onto High St",
  "distance_m": 200,
  "distance_text": "200 m",
  "road": "High St",
  "eta_min": 12,
  "remaining_m": 5400,
  "maneuver": "left",
  "lanes": [
    {"directions": ["straight"], "active": false},
    {"directions": ["left", "straight"], "active": true}
  ],
  "then_next": {
    "maneuver": "right",
    "distance_m": 400,
    "distance_text": "400 m",
    "instruction": "Turn right",
    "road": "Bridge Rd"
  },
  "ribbon_points": [
    {"x": 0, "y": 0},
    {"x": 0, "y": 120},
    {"x": -40, "y": 180}
  ],
  "ribbon_turn": 2,
  "junction": {
    "kind": "crossroads",
    "drive": "left",
    "outbound": "right",
    "through": true,
    "sides": [
      { "side": "left", "at": "before", "style": "dashed" },
      { "side": "left", "at": "at", "style": "dashed" }
    ]
  }
}
```

`maneuver` enum: `left`, `right`, `straight`, `slight_left`, `slight_right`, `u_turn`, `roundabout`, `arrive`, `depart`, `unknown`

Optional `lanes` (left→right): each lane lists allowed `directions` (same strings as `maneuver`) and whether it is `active` for the route. Omitted when the engine cannot provide lane guidance (e.g. MapKit, stock AIDL). Optional `then_next` is the following maneuver. Optional `remaining_m` is distance to destination.

Optional `ribbon_points` / `ribbon_turn`: local-unit corridor vertices (Y ahead, X right). Secondary path when `junction` is absent and the Pi cannot synthesize from `maneuver`. The Android companion may still fill these from a short public-OSRM probe.

Optional `junction` (**replaces** `minimap` — do not send geographic polylines): semantic turn-scene IR. Shared frame: approach from bottom, ahead toward top; proportions belong to the renderer. TypeScript: [`junction.ts`](junction.ts). Decision: [ADR 0013](../docs/adr/0013-junction-ir-replaces-minimap.md).

#### `junction` shared fields

| Field | Meaning |
|---|---|
| `kind` | Template family (required when `junction` present) |
| `drive` | `right` \| `left`; omit → `right` |
| `outbound` | Our exit relative to approach: `left` / `right` / `slight_*` / `straight` / `u_turn` |
| `through` | Main corridor continues past the decision |
| `sides[]` | Extra arms: `side` `left`\|`right`, `at` `before`\|`at`\|`after`, `style` `dashed`\|`solid` |

#### `junction` kinds (v1 draw + reserved)

| Kind | Extra fields | Diagram idea | v1 draw |
|---|---|---|---|
| `simple` | optional `sides` | Spine + outbound kink (+ stubs) | yes |
| `t_junction` | — | T bar; `through` false | yes |
| `crossroads` | — | + solid route, dashed others | yes |
| `fork` | outbound slight L/R | Y; route solid, other dashed | yes |
| `merge` | optional `side` | Side joins spine | yes |
| `dual_carriageway` | optional `cross_median` | Twin parallels; median gap if crossing | yes |
| `roundabout` | `exits` (2–6), `exit` (1-based) | Ring + ticks; ours solid | yes |
| `ramp_exit` | `through` true | Mainline + diverging slip | yes |
| `ramp_enter` | optional `side` | Slip → mainline | yes |
| `u_turn` | — | Canned U (flip with `drive`) | yes |
| `arrive` / `depart` | — | End/start mark on short spine | yes |
| `jughandle`, `interchange`, `gyratory` | — | Reserved; render as `simple` | no |

`cross_median`: set when `kind=dual_carriageway` and outbound is a hard left/right (not slight/straight). Dual detection is **inferred** on the companion (same-name opposite oneway, or parallel opposite oneway); OBF has no `dual_carriageway` tag.

Phone produces rich `junction` when possible (OsmAnd Full Library). When omitted, Pi synthesizes `{ kind, outbound }` from `maneuver` (`left`/`right`→`simple`, `slight_*`→`fork`, `roundabout`→`roundabout` exits=4 exit=2, etc.); `sides` empty. Unknown `kind` → `simple` fallback.

#### OsmAnd TurnType / classifier → `kind`

Maps through protocol `maneuver` first ([`ManeuverParser.fromOsmandTurnType`](../android/app/src/main/java/com/motohud/companion/Models.kt)); rich producers then upgrade `kind` from topology.

| OsmAnd `TurnType` | `maneuver` | Default / synthesized `kind` | Rich upgrade when |
|---|---|---|---|
| C (1) | `straight` | `simple` | dual → `dual_carriageway`; arms → `crossroads` |
| TL (2), TSHL (4) | `left` | `simple` | T / cross / dual / `cross_median` |
| TR (5), TSHR (7) | `right` | `simple` | same |
| TSLL (3), KL (8) | `slight_left` | `fork` | dual context may still be `dual_carriageway` |
| TSLR (6), KR (9) | `slight_right` | `fork` | same |
| TU (10), TRU (11) | `u_turn` | `u_turn` | — |
| RNDB (13), RNLB (14) | `roundabout` | `roundabout` | fill `exits`/`exit` when known |
| OFFR (12) | `unknown` | `simple` | — |
| (arrive / depart) | `arrive` / `depart` | `arrive` / `depart` | — |
| `*_link` highway diverge | (turn class) | `ramp_exit` | attached mainline continues |
| `*_link` highway merge | (turn class) | `ramp_enter` | slip joins spine |
| classifier: L+R+through arms | — | `crossroads` | — |
| classifier: one side, no through | — | `t_junction` | — |
| classifier: dual inferred | — | `dual_carriageway` | `cross_median` if hard L/R |

### `media`

```json
{
  "type": "media",
  "playing": true,
  "title": "Song Title",
  "artist": "Artist Name"
}
```

### `cmd`

```json
{
  "type": "cmd",
  "action": "play_pause"
}
```

`action` enum: `play_pause`, `next_track`, `prev_track`

### `heartbeat`

```json
{
  "type": "heartbeat",
  "ts": 1710000000
}
```

Phone writes heartbeat while linked. There is **no timeout / auto-unlink** on the Pi yet — `linked` flips when the BLE stack reports connect/disconnect (or stays true for HTTP-only bring-up).

## Dev HTTP injector (Pi)

When `motohud` is started with `-http :8787`, the hub exposes:

| Method | Path | Body | Effect |
|---|---|---|---|
| `GET` | `/health` | — | `ok` |
| `POST` | `/nav` | `nav` JSON | `ApplyNav` |
| `POST` | `/media` | `media` JSON | `ApplyMedia` |
| `POST` | `/button` | plain text `prev` / `next` / `action` / `*_long` | `HandleButtonEvent` |
| `GET` | `/frame.png` | — | current 1-bit frame |
| `GET` | `/preview/`, `/emulator/` | — | static web tools |

The Android companion can **also** POST `/nav` and `/media` to this base URL (emulator host loopback `http://10.0.2.2:8787`) while BLE is optional. HTTP has no `/heartbeat` and does not carry `cmd` notifies back to the phone — use BLE for button→media control, or press buttons via `/button` / the emulator UI.

Payload size: keep messages small (notification-sized). BLE writes use no-response; aim well under a single ATT MTU (~20–180 bytes typical without negotiation).

## Nav sources (companions)

Wire format is **engine-agnostic** ([ADR 0006](../docs/adr/0006-engine-agnostic-nav-android-osmand-ios-mapkit.md)): Android → OsmAnd (AIDL now; Full Library planned); iOS → MapKit; optional fields like `lanes` omitted when unavailable.

| Priority | Source | How | Notes |
|---|---|-----|---|
| 1a | **OsmAnd embedded** (`embedded` flavor) | Full Library `RoutingHelper` poll | Lanes, then-next, ETA, street, remaining |
| 1b | **OsmAnd AIDL** (`aidl` flavor) | `registerForNavigationUpdates` + voice + OsmAnd notif enrich | Typed turn/distance; soft road/ETA from notifications |
| 2 | Google Maps / Maps Go | `NotificationListenerService` text scrape | Fallback when OsmAnd is absent or not actively navigating |

While OsmAnd reports `active` navigation, Maps notification updates are ignored.

### OsmAnd tips

- Install [OsmAnd](https://play.google.com/store/apps/details?id=net.osmand) (`net.osmand`) or OsmAnd+ (`net.osmand.plus`).
- Start HUD link after OsmAnd is installed so the companion can bind `net.osmand.aidl.OsmandAidlServiceV2`.
- `TurnType` ints map to protocol `maneuver` (e.g. TL→`left`, TSLL/KL→`slight_left`, RNDB→`roundabout`).

### Google Maps tips

If nav fields are empty, disable Google Maps **Live Updates** / **Live info** notification categories in Android system settings for Maps, then restart navigation.

## Road ribbon / junction

Active nav with live geometry uses a **two-column** layout: left = junction diagram or corridor, right = compacted hero distance + road + ETA (no maneuver arrows).

- Prefer optional `junction`: semantic IR → idealized template by `kind` (immediate decision only).
- Else synthesize a minimal junction from `maneuver`.
- Else `ribbon_points` schematic corridor.
- Else synthetic kink from `maneuver` in the classic stack (glyph + distance + road + bottom ribbon); unknown → dashed placeholder.

`nav.minimap` (meter polylines) is **removed** from the live HUD path. Emulator/lab may still classify offline; production rich IR comes from OsmAnd Full Library, not AIDL.

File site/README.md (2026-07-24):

# Moto HUD site

Astro static project site deployed to GitHub Pages at
**https://lexwebb.github.io/moto-hud/**.

## Local

```bash
cd site
npm install
npm run build:wasm   # needs Go on PATH — builds public/emulator/motohud.wasm
npm run dev          # http://localhost:4321/moto-hud/
```

Without wasm, home / enclosure / design still work; the emulator page shows an error until `build:wasm` (or CI) produces the binary.

```bash
npm run build        # syncs GLB + route JSON, then astro build → dist/
npm run preview      # preview the production build
```

## Pages deploy

Push to `main` runs [`.github/workflows/pages.yml`](../.github/workflows/pages.yml):
Go WASM build → copy assets → `astro build` → GitHub Pages.

One-time: repo **Settings → Pages → Source: GitHub Actions**.

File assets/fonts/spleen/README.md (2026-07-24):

# Spleen (bitmap)

Monospaced pixel fonts by Frederic Cambus — https://github.com/fcambus/spleen  
License: BSD-2-Clause (see LICENSE).

Pregenerated sizes used by Moto HUD (exact BDF pixels, never scaled):

- `spleen-6x12.bdf` — meta / footers
- `spleen-8x16.bdf` — ETA / body
- `spleen-12x24.bdf` — road / titles
- `spleen-16x32.bdf` — distance

Do not generate intermediate sizes. If design needs another size, add another official Spleen BDF.

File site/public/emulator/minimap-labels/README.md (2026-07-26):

Drop accepted `*.accepted.json` label downloads here (route + context vectors + bitplanes).

Naming: `<fixture-id>.accepted.json` — the lab loads these automatically when you open that fixture.

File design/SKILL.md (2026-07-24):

---
name: moto-hud-design
description: Use this skill to generate well-branded interfaces and assets for the Moto HUD motorcycle e-ink heads-up display, either for production or throwaway prototypes/mocks/etc. Contains essential design guidelines, colors, type, fonts, assets, and UI kit components for prototyping.
user-invocable: true
---

Read the README.md file within this skill, and explore the other available files.
If creating visual artifacts (slides, mocks, throwaway prototypes, etc), copy assets out and create static HTML files for the user to view. If working on production code, you can copy assets and read the rules here to become an expert in designing with this brand.
If the user invokes this skill without any other guidance, ask them what they want to build or design, ask some questions, and act as an expert designer who outputs HTML artifacts _or_ production code, depending on the need.

Key constraints to always respect: 250×122px panel, 1-bit black/white only (no gray, no opacity — use dither patterns), thick square-capped strokes (1/2/3px), Terminus Bold at 12/16/24/32px only, no touch UI, no smooth animation (discrete steps only), no rounded corners, no shadows/gradients/blur.

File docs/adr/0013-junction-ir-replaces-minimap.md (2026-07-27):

---
status: accepted
date: 2026-07-28
---

# Semantics-first junction IR replaces meter minimap

Live nav left-column geometry is a **kind-discriminated junction IR** (`nav.junction`), not geographic polylines. The Pi draws idealized templates by `kind`; the phone fills rich topology when it can (OsmAnd Full Library), otherwise the Pi synthesizes `{ kind, outbound }` from `maneuver`. Immediate decision only — no interchange spaghetti on 70×80 e-ink. `dual_carriageway` is v1; dual detection is ours (OBF has no tag).

## Considered options

- **Chosen** — semantic IR + template draw; replace `nav.minimap`; phone optional / Pi fallback.
- **Rejected: keep meter polylines** — RDP/octilinear still looks geographic and fights the panel size.
- **Rejected: keep minimap beside junction** — two geometry paths; HUD must pick one.
- **Rejected: wait for OsmAnd `dual_carriageway` tag** — not in OBF routing encoding; infer from oneway + bearings.

## Consequences

- Wire: optional `junction` on `nav`; omit `minimap`. Prefer junction over ribbon; ribbon when neither junction nor synthesizable maneuver exists.
- Schema: [`protocol/junction.ts`](../../protocol/junction.ts); kinds and mapping in [`protocol/README.md`](../../protocol/README.md).
- Producers: Full Library only for rich IR; AIDL stays thin; emulator/classifier is lab.
- Unknown `kind` → render as `simple` using `outbound` / `sides`.

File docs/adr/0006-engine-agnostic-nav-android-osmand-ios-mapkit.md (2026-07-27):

---
status: accepted
date: 2026-07-27
---

# Engine-agnostic nav protocol; OsmAnd on Android, MapKit on iOS

The BLE/`nav` JSON schema is **engine-agnostic**. Platform companions fill it from different nav engines. **Android** targets **OsmAnd** (AIDL today; Full Library / richer fields including lanes as we own the flow — GPL and APK size are acceptable for this open-source project). **iOS** will use **Apple MapKit** `MKDirections` plus a local guidance loop so we avoid self-hosting Valhalla or paying a directions SaaS. Optional fields such as `lanes[]` are omitted when an engine cannot provide them.

## Considered options

- **Chosen** — shared protocol; OsmAnd-class richness on Android; MapKit for free iOS routing hosted by Apple.
- **Rejected: self-hosted Valhalla / GraphHopper for iOS** — ongoing infra cost unfit for this OSS project.
- **Rejected: OsmAnd as the cross-platform engine** — no usable iOS embed SDK; AIDL/Full Library are Android-only.
- **Rejected: Magic Lane / HERE / Mapbox as required path** — not free for production.
- **Rejected: Google Maps scrape as the long-term source** — brittle; kept as Android fallback only.

## Consequences

- iOS will lag Android on lanes, motorcycle profiles, and offline routing; the Pi must tolerate missing optional fields.
- Do not put OsmAnd `TurnType` ints or MapKit types on the wire — map to protocol `maneuver` / `lanes` in the companion.
- Near-term Android work can deepen AIDL then move to Full Library without changing the Pi contract.
- Full Library ships as an on-demand Play Feature Delivery module (see ADR 0009) so the base install stays AIDL-sized.

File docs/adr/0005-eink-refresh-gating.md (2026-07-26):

---
status: accepted
date: 2026-07-26
---

# Gate e-ink redraws on maneuver and coarse distance

Because e-ink updates are slow and visually noisy, the hub/emulator only redraw on **maneuver / road / screen changes**, **≈50 m distance buckets**, or **force** — not every GPS tick. LCD hosts skip the e-ink gate.

## Consequences

- Distance shown on e-ink is stepped (nearest ~50 m), not metre-accurate live countdown.
- Busy panel queues at most one pending force refresh.

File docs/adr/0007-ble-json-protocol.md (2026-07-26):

---
status: accepted
date: 2026-07-01
---

# BLE GATT with small JSON messages (nav / media / cmd / heartbeat)

Phone↔Pi link uses a custom GATT service (**MotoHUD**) with JSON payloads for `nav`, `media`, `cmd`, and `heartbeat`. Same JSON shapes are reused by the Pi’s HTTP injector for bring-up without BLE. Payloads stay notification-sized for typical ATT MTUs.

## Considered options

- **Chosen** — JSON over BLE characteristics (simple to debug, shared with HTTP/WASM tools).
- **Rejected: protobuf/binary-only** — harder to poke from emulator and curl; size win not worth it at HUD rates.
- **Rejected: Classic Bluetooth SPP** — BLE fits phone background + low power better for this form factor.

## Consequences

- Optional rich fields (`ribbon_points`, `minimap`, future `lanes`) must stay compact or the link needs MTU negotiation / chunking later.
- Schema documented in `protocol/README.md` and mirrored in Go + Kotlin.

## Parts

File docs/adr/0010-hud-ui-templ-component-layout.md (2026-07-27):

---
status: accepted
date: 2026-07-27
---

# HUD UI: templ components, layout props, pure render tree

The Pi compositor will move from hand-built SVG strings in `layout.go` toward **compile-time templ components** plus a small **integer flex layout** layer (`Row` / `Col` / `Box`) that emits SVG groups. Components are **pure functions of props and `RenderContext`** (faces, tokens, canvas size); side effects (BLE, refresh gating, rasterize) stay in the hub. The browser design kit (`design/`) remains the visual reference; Go components mirror the same primitive names and tokens.

## Considered options

- **Chosen** — templ for markup/ergonomics; in-repo layout subset (gap, pad, justify, align, baseline rows with `pixelfont` measure); no embedded JS/React on device.
- **Rejected: runtime React in Go** — too heavy for Pi Zero; SVG needs a custom host anyway.
- **Rejected: gomponents-only** — viable but weaker “screen file” DX vs templ for nested HUD trees.
- **Rejected: full CSS/grid engine** — 250×122 instrument panel does not justify it.

## Consequences

- New package(s) under `pi/internal/hudui/` (or similar): layout pass → SVG serialize; existing `pixelfont` + `RasterizeSVG` path unchanged.
- Screen migration is incremental (one kit screen at a time); `layout.go` shrinks as screens move.
- **Scene IR** ([0012](0012-hud-scene-ir-svg-backend.md)) is the compose/engine contract; SVG strings are backend-only.
- **Screens** are authored in `hudui/screens/*.templ`; they emit **scene nodes** via `hudui/scenetempl` (not inline SVG). Compose calls `scenetempl.Render(...)` and wraps the main column with `ChromeFrameBody` in `FrameVars`.
- Shared tokens should converge with `design/tokens/` (codegen or checked-in JSON) to limit drift.
- Interactive “hooks” are not a runtime: state lives on `hud.State`; preview interactivity uses the same props from tests or emulator, not `useEffect` in components.
- Refresh tiers, fixed slots, and spatial partial orchestration are specified in [ADR 0011](0011-component-refresh-tiers-partial-regions.md).

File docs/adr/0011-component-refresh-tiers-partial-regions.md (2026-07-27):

---
status: accepted
date: 2026-07-27
---

# Component refresh tiers and spatial partial updates

HUD components declare a **refresh tier** and, when eligible, a **fixed layout slot** (`image.Rectangle` in canvas space). After each state update, a **refresh orchestrator** compares stable **change keys** per component (not SVG string diffs), unions dirty rectangles, and chooses: **no draw**, **spatial partial** (Waveshare only), **full bitmap + partial waveform**, or **full bitmap + full waveform** (ghosting cadence per ADR 0004). Semantic gating (ADR 0005) remains the first filter; tiers refine *what* to recomposite and *how much* of the panel to push over SPI.

Today Waveshare “partial” is only a **faster full-frame update mode** (`setWindow` covers the whole panel). This ADR adds **optional spatial windows** when the dirty union is small enough and only **partial-capable** components changed.

## Component metadata

Each primitive or screen region exposes (compile-time or layout-time constants where possible):

| Field | Purpose |
|---|---|
| `Tier` | `Static` · `Slow` · `Fast` · `PartialOK` |
| `Slot` | Fixed `Rect` after layout; required for `PartialOK` |
| `ChangeKey(props)` | Hashable value(s) that mean “pixels in this slot may differ” |

**Tier semantics (intent):**

- **Static** — chrome, rules, footer hints on a given screen; redraw on screen/mode change or forced full refresh only.
- **Slow** — road name, media title, maneuver glyph; redraw when matching protocol fields change (or screen change).
- **Fast** — distance bucket, ETA, link heartbeat; may change under ADR 0005 without other nav fields changing.
- **PartialOK** — same as Fast/Slow for change detection, but **allowed** to participate in a spatial partial upload if its slot is stable and dirty area is below policy threshold.

Components that **reflow siblings** (flex grow, variable-width text outside a fixed slot) must **not** be `PartialOK`; they force at least a **full recomposite** of the affected column (often the whole main area).

## Orchestrator decision flow

```text
BLE / button → RefreshGate (ADR 0005) → if !ShouldRedraw → stop
                ↓
         Build props per component → ChangeKey vs last frame
                ↓
         Dirty set = components whose keys changed
                ↓
    All dirty ⊆ PartialOK AND union(Slot) area ≤ maxPartialPixels?
         yes → raster dirty slots (or layers) → display.ShowRegion(rects, bitmap)
         no  → full Render() → display.Show(full)  [partial or full waveform per ADR 0004]
                ↓
    partialsSinceFull++; at N → force full waveform + driver re-init (existing Waveshare logic)
```

**Policy knobs** (defaults tuned on hardware):

- `maxPartialPixels` — e.g. 30–40% of canvas; above → full frame recomposite even if components are PartialOK.
- `maxPartialCount` — already `waveshareFullEveryN` (5); spatial partials count toward the same counter.
- **Alignment** — dirty rects expanded to **8px horizontal** boundaries before `setWindow` (EPD byte columns).

The orchestrator **does not** infer dirtiness from SVG or raster diffs in v1; **explicit ChangeKey** keeps Pi cost predictable and matches protocol-shaped updates.

## Rendering engine responsibilities

1. **Compose** (`hudui/compose` + templ) assigns stable slots, change keys, tiers, and optional `Patch` closures per layer in `plan.ScreenPlan`. The `hud` engine and orchestrator consume that plan only — they do not embed screen-specific geometry.
2. **Retain** last frame grayscale buffer on hosts that support spatial partial.
3. **On partial path** — call each dirty layer’s `Patch()`, blit at `Layer.Slot`, crop to aligned union, pass to display.
4. **On full path** — `BodySVG` from the plan plus chrome shell → `BuildPixelSVGFromVars` → rasterize entire 250×122.

`templ` components stay pure; tier/slot/key/patch live on compose layout nodes (`plan.Layer`). The BLE link glyph uses a fixed chrome slot (`NodeLink`, `TierPartialOK`) and is composited after the shell SVG (full frame and spatial patch).

## Display host capabilities

| Host | Spatial partial | Waveform partial | Notes |
|---|---|---|---|
| `waveshare` | Optional (`ShowRegion`) | Yes (ADR 0004) | Implement sub-window `setWindow` + subset SPI write |
| `inky` | No | No | Always full frame, ~20s |
| `lcd`, `png`, `emu` | N/A | N/A | Full buffer each draw; emulator should visualize dirty rects for debug |

`Display` interface grows a capability-based API, e.g. `Show(img)` unchanged as default full frame; `RegionalDisplay` or optional `ShowPartial(img, []image.Rectangle)` for Waveshare.

## Considered options

- **Chosen** — declarative tiers + change keys + union rect policy; orchestrator above compositor; extend Waveshare driver for real windows when profitable.
- **Rejected: framebuffer auto-diff** — too CPU-heavy on Pi Zero; fragile with dither/anti-alias thresholds.
- **Rejected: SVG tree diff** — expensive; layout shift breaks bbox assumptions.
- **Rejected: spatial partial without fixed slots** — flex reflow makes correct dirty regions impractical.

## Consequences

- ADR 0010 layout layer must support **fixed slots** for PartialOK components; distance readout is the first candidate.
- `RefreshGate` may shrink to coarse “any nav tick worth considering” while orchestrator handles Fast vs Static within an allowed redraw.
- Tests: golden full frames plus unit tests on orchestrator decisions (dirty set → full vs partial).
- Emulator gains optional “highlight dirty rect” mode for tuning `maxPartialPixels`.

## Related

- [0004](0004-waveshare-partial-refresh.md) — partial vs full **waveform** cadence
- [0005](0005-eink-refresh-gating.md) — when updates are considered at all
- [0010](0010-hud-ui-templ-component-layout.md) — templ components and layout

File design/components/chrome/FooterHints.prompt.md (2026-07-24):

Bottom-edge button legend, 11px, right-aligned so each hint sits near its physical button, bold button name + plain action word.

```jsx
<FooterHints hints={[{btn:'PREV',label:'Mode'},{btn:'NEXT',label:'Skip'},{btn:'HOLD',label:'Home'}]} />
```

Keep to 2–3 entries — this row must never compete with the hero content above it. Omit entirely on screens where the legend would be redundant (e.g. once the user has learned it).

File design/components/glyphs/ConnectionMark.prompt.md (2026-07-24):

Compact BLE link/heartbeat status mark for the corner of every screen.

```jsx
<ConnectionMark connected={true} heartbeat={true} />
```

Bolt glyph = connected, X = disconnected. The trailing square dot blinks in discrete steps (never a smooth fade/pulse — matches the slow-refresh, no-smooth-animation rule) when a heartbeat is present.

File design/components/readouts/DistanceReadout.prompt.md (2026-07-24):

The hero number on the Nav screen — distance to the next maneuver.

```jsx
<DistanceReadout value="350" unit="m" size="hero" />
```

Unit (m/km) rides as a small suffix glyph, not a settings toggle — "compact unit switching as typography." Use `size="secondary"` at 17px for less-important numeric rows (e.g. ETA).

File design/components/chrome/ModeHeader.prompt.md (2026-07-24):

Top-of-panel row: 11px mode label at left, `ConnectionMark` at right.

```jsx
<ModeHeader mode="NAV" connected heartbeat />
```

Always present so a glance confirms both "what screen is this" and "is the phone still talking to me" in the same 0.1s.

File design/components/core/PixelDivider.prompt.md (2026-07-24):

Thin full-width rule used to separate chrome rows from content.

```jsx
<PixelDivider variant="dashed" />
```

Three variants: `solid` (default), `dashed` (softer separation), `dither` (checkerboard pattern — this system's substitute for gray/opacity, since 1-bit e-ink has no gray).

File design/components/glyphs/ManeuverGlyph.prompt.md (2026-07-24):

Hero pixel-grid arrow glyph for the current navigation maneuver — the first thing the eye lands on in a glance.

```jsx
<ManeuverGlyph type="left" size={40} />
```

Variants: left, right, slight-left, slight-right, straight, u-turn, roundabout, arrive, depart, unknown (renders a bold "?"). All strokes are 3px and square-capped — no rounded caps, no anti-aliasing tricks. Drawn as vector for preview; production raster pipeline thresholds it to 1-bit.

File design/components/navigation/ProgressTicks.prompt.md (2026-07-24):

Discrete tick-block bar standing in for a progress-to-turn indicator.

```jsx
<ProgressTicks total={5} filled={3} />
```

Each tick is a small filled/empty square, matching the instrument-panel bold-stroke language. Only step the `filled` count at coarse distance thresholds (e.g. every 100m) — this is explicitly not a smooth-filling bar, since the panel can't refresh fast enough to animate one.

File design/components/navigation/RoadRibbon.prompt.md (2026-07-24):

Quiet 40px-tall band that schematizes the upcoming corridor as a bold kinked line — never a geographic map, never map tiles/streets. Oriented vertically: the spine runs bottom-to-top representing "ahead," with the line kinking sideways where a turn approaches — like a compressed forward view, not a left-right timeline.

```jsx
<RoadRibbon points={[{x:110,y:0},{x:110,y:24},{x:170,y:36}]} turnIndex={1} />
```

No `points` (or fewer than 2) renders a dashed flat line meaning "no corridor data yet" rather than an empty gap. Updates only on maneuver change or coarse distance thresholds, never a smooth scroll — the caller should only re-pass new points on those events.

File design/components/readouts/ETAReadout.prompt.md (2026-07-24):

Optional small ETA line, 13px, sits below the hero distance.

```jsx
<ETAReadout etaMin={12} />
```

Renders nothing when `eta_min` wasn't in the packet — never show a placeholder dash for a field the phone didn't send.

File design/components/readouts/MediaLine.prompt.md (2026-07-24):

Now-playing row: play/pause glyph + title (13px bold) + artist (11px). Used full-size on the Media screen, or shrunk as a secondary line under Nav.

```jsx
<MediaLine playing title="Night Drive" artist="Field Tapes" />
```

No cover art — deliberately excluded, see readme "data limits" note. Long titles truncate with ellipsis rather than wrap or scroll.

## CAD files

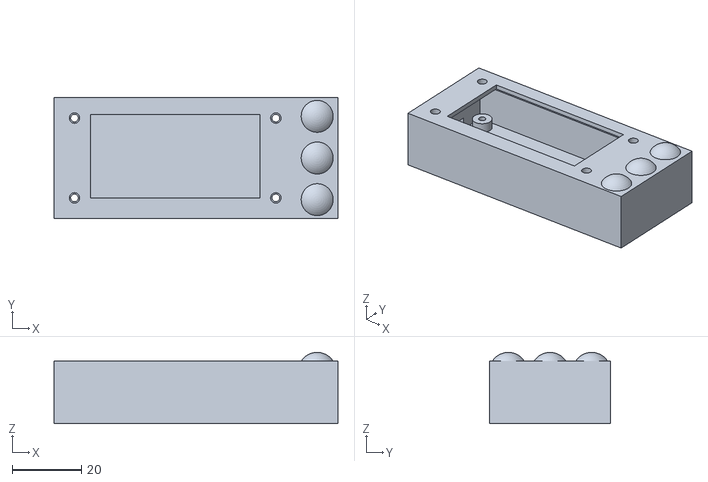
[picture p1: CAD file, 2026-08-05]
enclosure/exports/assembly.stl
81.8 x 34.8 x 20.5

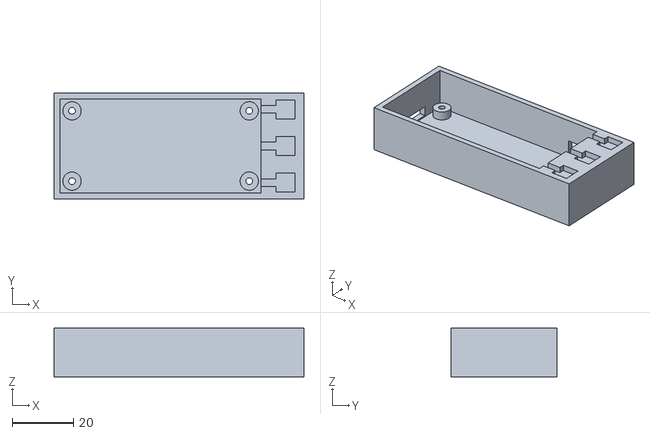
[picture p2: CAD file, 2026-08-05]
enclosure/exports/base.stl
81.8 x 34.8 x 16.0

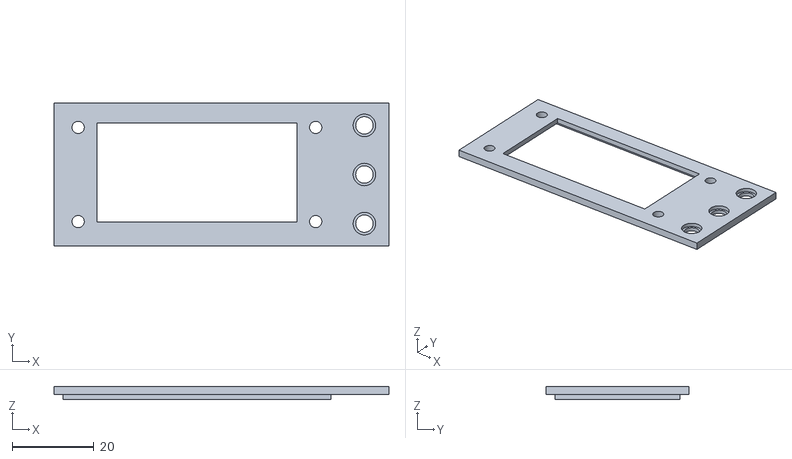
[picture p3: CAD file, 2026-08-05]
enclosure/exports/lid.stl
81.8 x 34.8 x 3.20

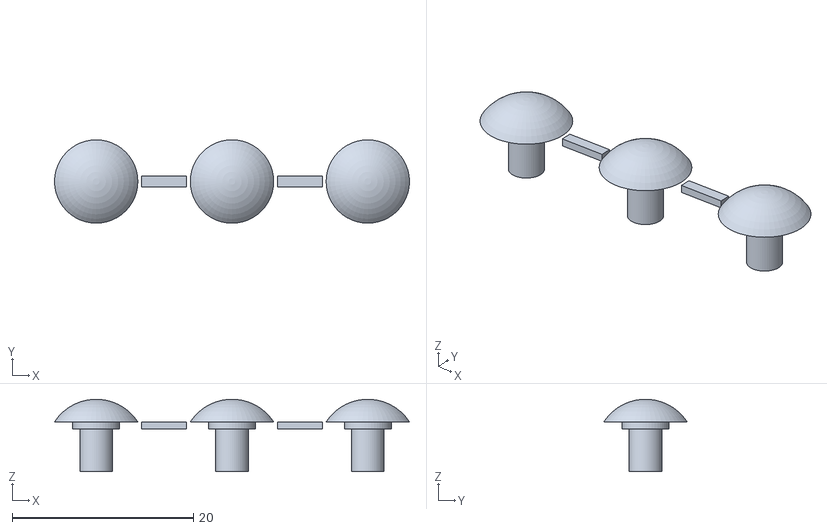
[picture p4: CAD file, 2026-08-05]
enclosure/exports/caps.stl
39.2 x 9.21 x 7.99

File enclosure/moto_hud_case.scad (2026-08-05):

// Moto HUD bench enclosure — Pi Zero + display HAT clamshell
// Units: millimetres
//
// Usage (Customizer / CLI):
//   part = "assembly" | "base" | "lid" | "caps"
// Preview: F5   Render + export STL: F6 → File → Export
// CLI:
//   openscad -D 'part="base"' -o exports/base.stl moto_hud_case.scad
//   openscad -D 'part="lid"' -o exports/lid.stl moto_hud_case.scad
//   openscad -D 'part="caps"' -o exports/caps.stl moto_hud_case.scad
//   openscad -D 'part="assembly"' -o exports/assembly.stl moto_hud_case.scad

/* [Part] */
part = "assembly"; // [assembly, base, lid, caps]
explode = 0;       // [0:0.5:12] lid lift for assembly preview (mm)
cap_index = -1;    // [-1:1:2] caps export: -1 = all three on a sprue; 0/1/2 = one cap

/* [Board stack — caliper-check these] */
// Raspberry Pi Zero PCB footprint
board_w = 65.0;
board_d = 30.0;
// Pi PCB + header + HAT stack height (Inky ~8.5; leave headroom for Waveshare too)
stack_h = 14.0;
// Usable glass (Inky / Waveshare 2.13″ ~48.5 × 23.8)
window_w = 48.5;
window_d = 23.8;
// Window offset from board origin (Pi Zero corner = 0,0); tune after measuring HAT
window_ox = (board_w - window_w) / 2;
window_oy = (board_d - window_d) / 2 + 0.5;

/* [Enclosure] */
wall = 2.0;
floor_t = 2.0;
lid_t = 2.0;
clearance = 0.4;     // lateral fit around boards
print_tol = 0.3;     // extra cutout looseness
split_z = floor_t + stack_h; // cavity height inside base before lid

/* [Screws — Pi Zero M2.5 holes] */
// Hole centres from board corner (official Zero mechanical)
hole_inset = 3.5;
screw_d = 2.7;       // clearance for M2.5
boss_od = 6.0;
boss_id = 2.2;       // pilot / self-tap
boss_h = 3.0;

/* [USB / SD cutouts] */
// Pi Zero: micro-USB power on long edge near corner; Zero 2 W uses USB-C — widen if needed
usb_w = 10.0;
usb_h = 5.0;
sd_w = 14.0;
sd_h = 3.0;
sd_enable = true;

/* [Buttons — lid face, on right-hand side rail] */
// cap = printed mushroom + 6×6 tactile wells; panel8 = 8 mm high-head panel holes
button_mode = "cap"; // [cap, panel8]
button_count = 3;
button_pitch = 12.0; // centres; leave clearance between ~11 mm caps
button_rail = 12.0;  // extra case width on +X for buttons (SD stays on -X)
button_ox = 6.0;     // button centre X from outer right edge, inward
// Order along +Y (rail on right, screen upright): Prev, Next, Action

// Cap mode (Path A′) — glove target is the print; electrical is the tactile
cap_od = 11.0;
cap_dome_h = 2.5;
stem_d = 3.6;
stem_clear = 0.35;
stem_len = 5.5;      // through lid + travel into tactile
flange_d = 5.2;      // retention flange under dome (wider than shaft)
flange_h = 0.8;
retention_h = 1.0;   // underside counterbore depth in lid
travel = 1.2;
tactile_foot = 6.2;  // 6×6 body + fit
tactile_h = 3.5;     // body height — caliper after purchase and retune
well_depth = 2.0;
wire_ch_w = 2.5;
wire_ch_h = 2.0;

// panel8 fallback
button_d = 8.2;

/* [Quality] */
$fn = 48;

// ---------------------------------------------------------------------------
eps = 0.02;

outer_w = board_w + 2 * (wall + clearance) + button_rail;
outer_d = board_d + 2 * (wall + clearance);
cavity_w_board = board_w + 2 * clearance;
cavity_d = board_d + 2 * clearance;

// Board XY origin: left/front inside walls; rail sits on +X
board_x = wall + clearance;
board_y = wall + clearance;

shaft_d = stem_d + print_tol + stem_clear;
rail_x0 = wall + cavity_w_board; // start of solid +X rail (inside cavity wall)

function hole_xy(i, j) = [
    hole_inset + i * (board_w - 2 * hole_inset),
    hole_inset + j * (board_d - 2 * hole_inset)
];

// Button centres on the +X rail; n = 0..button_count-1 → Prev, Next, Action
function button_xy(n) = [
    outer_w - button_ox,
    board_y + (board_d - (button_count - 1) * button_pitch) / 2 + n * button_pitch
];

module at_board_xy() {
    translate([board_x, board_y, 0])
        children();
}

module screw_boss_solids(h = boss_h) {
    // Overlap floor slightly so CSG unions cleanly (avoid coplanar seams)
    translate([board_x, board_y, floor_t - eps])
        for (i = [0, 1], j = [0, 1]) {
            p = hole_xy(i, j);
            translate([p[0], p[1], 0])
                cylinder(h = h + eps, d = boss_od);
        }
}

module screw_boss_pilots(h = boss_h) {
    translate([board_x, board_y, floor_t - eps])
        for (i = [0, 1], j = [0, 1]) {
            p = hole_xy(i, j);
            translate([p[0], p[1], -eps])
                cylinder(h = h + 3 * eps, d = boss_id);
        }
}

module screw_holes_xy(z0, h, d) {
    translate([board_x, board_y, z0])
        for (i = [0, 1], j = [0, 1]) {
            p = hole_xy(i, j);
            translate([p[0], p[1], -eps])
                cylinder(h = h + 2 * eps, d = d);
        }
}

module usb_cutout() {
    // Through back wall (+Y), assuming Pi Zero power edge faces rear
    translate([
        board_x + board_w - usb_w - 1.5,
        outer_d - wall - clearance - eps,
        floor_t + 1.0
    ])
        cube([usb_w + print_tol, wall + clearance + 2 * eps, usb_h + print_tol]);
}

module sd_cutout() {
    if (sd_enable)
        translate([
            -eps,
            board_y + (board_d - sd_w) / 2,
            floor_t + 0.5
        ])
            cube([wall + clearance + 2 * eps, sd_w + print_tol, sd_h + print_tol]);
}

// --- Buttons ----------------------------------------------------------------

module button_panel8_holes() {
    for (n = [0 : button_count - 1]) {
        p = button_xy(n);
        translate([p[0], p[1], -eps])
            cylinder(h = lid_t + 2 * eps, d = button_d + print_tol);
    }
}

module button_cap_shafts() {
    // Lid coords: z=0 underside (toward cavity), z=lid_t outer face.
    // Cap drops in from outside: flange seats in outer counterbore; stem hangs toward tactile.
    for (n = [0 : button_count - 1]) {
        p = button_xy(n);
        translate([p[0], p[1], -eps])
            cylinder(h = lid_t + 2 * eps, d = shaft_d);
        translate([p[0], p[1], lid_t - retention_h])
            cylinder(h = retention_h + eps, d = flange_d + print_tol);
    }
}

module tactile_wells() {
    for (n = [0 : button_count - 1]) {
        p = button_xy(n);
        translate([
            p[0] - tactile_foot / 2,
            p[1] - tactile_foot / 2,
            split_z - well_depth
        ])
            cube([tactile_foot, tactile_foot, well_depth + eps]);
    }
}

module wire_channels() {
    // Channel from each well toward the board cavity (−X), open at top of rail
    for (n = [0 : button_count - 1]) {
        p = button_xy(n);
        ch_x0 = rail_x0 - eps;
        ch_len = p[0] - tactile_foot / 2 - ch_x0 + eps;
        if (ch_len > 0)
            translate([
                ch_x0,
                p[1] - wire_ch_w / 2,
                split_z - wire_ch_h
            ])
                cube([ch_len, wire_ch_w, wire_ch_h + eps]);
    }
}

module button_cap_solid() {
    // Origin at flange top (= lid outer face when seated). Dome +Z; stem −Z through lid.
    union() {
        // Domed head
        intersection() {
            translate([0, 0, -cap_od / 2 + cap_dome_h])
                sphere(d = cap_od);
            translate([-cap_od, -cap_od, 0])
                cube([2 * cap_od, 2 * cap_od, cap_dome_h + eps]);
        }
        // Flange seats in outer counterbore
        translate([0, 0, -flange_h])
            cylinder(h = flange_h + eps, d = flange_d);
        // Stem through lid toward tactile
        translate([0, 0, -stem_len])
            cylinder(h = stem_len, d = stem_d);
    }
}

module caps_sprue() {
    // Print flange-down (stem into bed support / or float with brim); dome up.
    pitch = cap_od + 4;
    lift = stem_len; // sit stem tips on Z=0 for flat bed contact option
    if (cap_index >= 0 && cap_index < button_count) {
        translate([0, 0, lift])
            button_cap_solid();
    } else {
        for (n = [0 : button_count - 1]) {
            translate([n * pitch, 0, lift])
                button_cap_solid();
            if (n < button_count - 1)
                translate([n * pitch + cap_od / 2 - 0.5, -0.6, lift - flange_h])
                    cube([pitch - cap_od + 1, 1.2, 0.8]);
        }
    }
}

module caps_in_assembly() {
    // Seat caps in lid shafts: flange in retention recess, dome proud of outer face
    for (n = [0 : button_count - 1]) {
        p = button_xy(n);
        translate([p[0], p[1], split_z + explode + lid_t])
            button_cap_solid();
    }
}

// --- Shells -----------------------------------------------------------------
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

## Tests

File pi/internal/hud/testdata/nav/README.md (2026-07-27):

# Nav classic golden

Locks full-frame raster for active classic nav (no ribbon/minimap).

```bash
cd pi
UPDATE_NAV_CLASSIC_GOLDEN=1 go test ./internal/hud/ -run NavClassicGolden
```

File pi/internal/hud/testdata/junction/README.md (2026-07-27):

# Junction IR templates

Semantic (not meter) drawer that will replace `MinimapNodes` once
`PreferJunctionTemplates` is the live default.

## Hook points

| Path | Role |
|---|---|
| `pi/internal/hud/junction.go` | `JunctionNodes` templates + `PreferJunctionTemplates` flag |
| `pi/internal/hud/minimap.go` | Legacy meter polyline path (keep until flag flips) |
| `pi/internal/hudui/compose/nav_live.go` | Left column prefers junction when deps.HasJunction |
| `site/src/pages/junction-lab.astro` | Preview POC JSON (`emulator/junction-poc/*.json`) |
| `MotoHUD.junctionSVG` (WASM) | Optional SVG fragment from junction IR JSON |

## Kinds drawn (v1)

`simple`, `t_junction`, `crossroads`, `fork`, `merge`, `dual_carriageway`,
`roundabout`, `ramp_exit`, `ramp_enter`, `u_turn`, `arrive`, `depart`.

Site mirror: `site/src/scripts/junction-draw.js` (`IMPLEMENTED_KINDS`).

## Preview

```bash
# Go unit tests (no WASM rebuild required)
cd pi && go test ./internal/hud/ -run Junction -count=1

# Lab UI (Astro site)
cd site && npm run dev
# open /moto-hud/junction-lab/
```

Set `hud.PreferJunctionTemplates = true` in a local build to route live HUD
through IR templates (synthesizes from `maneuver` when `nav.junction` is absent).

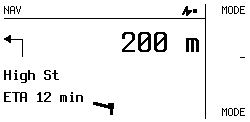
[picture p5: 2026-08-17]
pi/internal/hud/testdata/nav/classic-active.png

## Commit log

2026-07-24 Initial moto-hud: Pi Go HUD, Android companion, SVG+Spleen UI
    E-ink motorcycle nav/media HUD with BLE protocol, HTTP bring-up
    preview at native 250×122, and Inky/PNG display paths.
2026-07-24 Adopt Terminus Bold and port design-system HUD layouts
    Switch embedded BDFs from Spleen to Terminus Bold, vendor the Claude
    Design pack (Terminus-sized tokens) under design/, and reshape nav/
    media/status SVGs to match the instrument chrome (mode header, link
    mark, legend column, progress ticks, design maneuver glyphs).
2026-07-24 Improve emulator e-ink refresh and use a real street route
    Replace the fake polyline with an OSRM Whitehall→Farringdon path, and
    emulate panel refresh as on→off flash then fade-in with ≈50 m steps.
2026-07-24 Add parametric OpenSCAD bench enclosure with browser preview.
    [assembly.stl, base.stl, lid.stl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]
2026-07-24 Add Go hub tests, CI, Android HTTP sink, and protocol docs.
    Cover button routing and HTTP injector paths without hardware; companion can POST nav/media to local motohud for Wi-Fi bring-up.
2026-07-26 Add multi-host display backends, Waveshare partial refresh, and minimap.
    Support Inky/Waveshare/LCD via -host, emulate device refresh profiles (Waveshare partial ~0.3s with full every 5), and ship corridor minimap rendering with fixtures.
2026-07-27 feat(pi): hudui templ layer, refresh orchestrator, distance patches
    - Add hudui: tokens, flex layout, templ NavIdle screen, compose bridge
    - Add RefreshOrchestrator, nav slot map, Engine with distance slot patching
    - Wire motohud/WASM through RenderWithEngine and display.FrameMeta
    - MemoryScreen records partial refresh metadata for emulator
    - Accept ADR 0009/0010; document generate-hudui.sh
2026-07-27 feat(pi): spatial EPD windows, multi-slot patches, templ media/status
    - Waveshare ShowFrame uploads EPD sub-windows when FrameMeta.Spatial
    - packEPD213Window + canvas→EPD bounds helpers
    - Patch ETA/road/media title+artist; engine applies multi-node spatial patches
    - Media/status screens via templ; refresh slots for media partials
    - platform.Screen aliases display.Display for ShowFrame wiring
2026-07-27 Drive HUD refresh slots from compose plans, not hud renderer
    Move classic/live nav layout, layers, and patch closures into hudui/compose.
    Hud engine orchestrates plan descriptors only; remove legacy slot maps and
    live-nav fallback. Document plan-owned metadata in ADR 0010.
2026-07-27 Move HUD chrome shell into templ and compose.FrameVars
    Add screens/chrome.templ and compose chrome geometry plus legend hints.
    Hud layout and engine use FrameVars instead of hand-built chromeShell.
    Rename compose body_templ.go to screen_bodies.go so templ generate does not delete it.
2026-07-27 Track HUD test PNGs and plan-drive BLE link glyph
    - gitignore: allow pi/internal/hud/testdata/**/*.png
    - NodeLink layer on every screen plan with fixed chrome slot and patch
    - Chrome templ leaves empty link group; engine and Render blit link layer
    - Remove linked from nav/media screen keys; static hud_chrome descriptor key
    - LinkMarkFragment lives in compose; hud delegates for legacy callers
2026-07-27 Fix CI: track minimap golden PNGs ignored by *.png
    Root .gitignore excluded all PNGs, so TestMinimapGolden failed on
    CI with missing goldens. Allow pi/**/testdata/**/*.png and commit
    the fixtures.
2026-07-27 Update minimap SVG goldens to match current renderer
    Regenerated alongside the PNG fixtures (context group wrapper).
2026-07-27 Migrate HUD bodies and chrome to scene IR (ADR 0012)
    ScreenPlan.Body is []scene.Node; chrome frame built in Go with scene.Line.
    Media, status, idle, classic, and live nav columns use scene.Builder.
    SVG serialization only in render/svg; RawSVG for ribbon/minimap/lanes.
2026-07-27 Wire hudui screens through templ into scene IR.
    Add scenetempl bridge so .templ components emit scene nodes at compose time and remove duplicate Go body builders.
2026-08-02 Add Docker armv6 BLE cross-compile for Pi Zero.
    Build BlueZ-enabled motohud via buildx/QEMU instead of on-device Go, and wire it into prepare-bootfs by default.
2026-08-02 Wire prepare-bootfs to Docker BLE cross-compile by default.
2026-08-05 Add printed button caps and Pi Zero soldering guide.
    Enclosure gets mushroom actuators over 6×6 tactile wells (panel8 fallback), with docs for underside GPIO wiring on BCM 5/6/13.
    [assembly.stl, base.stl, caps.stl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]
2026-08-17 Replace SVG/canvas rasterization with a scene→1-bit bitmap renderer.
    Full frames, patches, minimap/junction panes, Pi, and WASM now paint from the scene IR, dropping tdewolff/canvas from the runtime path.
